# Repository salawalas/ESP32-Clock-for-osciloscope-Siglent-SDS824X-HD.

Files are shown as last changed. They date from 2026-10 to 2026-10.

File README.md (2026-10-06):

# Zegar RTC dla Siglent SDS800X HD (ESP32 + DS3231 + W5500)

Pudełko, które po włączeniu wysyła do oscyloskopu aktualną datę i godzinę (SCPI po TCP, port 5025).
Czas pochodzi z DS3231 (działa bez sieci), a gdy w zasięgu jest skonfigurowane Wi-Fi, jest odświeżany z NTP.

## Połączenia (ESP32 DevKit C)

| Moduł  | Pin modułu | GPIO ESP32 |
|---|---|---|
| DS3231 | SDA / SCL | 21 / 22 |
| W5500  | SCLK | 18 |
| | MISO | 19 |
| | MOSI | 23 |
| | SCS | 5 |
| | INT | 4 |
| | RST | 16 |
| oba | zasilanie, GND | 3V3 (lub 5V wg opisu na module W5500 - tylko jedno z nich), GND |

Piny zmienisz w `main/pins.h`. Kabel Ethernet idzie prosto z W5500 do portu LAN oscyloskopu.
Przycisk BOOT na płytce = "wyślij czas do oscyloskopu teraz".

## Ustawienia w oscyloskopie

LAN: stały adres IP `192.168.77.2`, maska `255.255.255.0`, brama pusta. Wyłącz w menu daty/czasu
synchronizację NTP przy starcie, żeby nie nadpisywała czasu z pudełka.

## Budowanie

ESP-IDF >= 5.3 (testowane tylko na papierze, patrz uwaga na końcu):

    idf.py set-target esp32
    idf.py build flash monitor

Sterownik W5500:
- IDF 5.3-5.5: wbudowany; `sdkconfig.defaults` go włącza (menuconfig -> Component config -> Ethernet -> SPI Ethernet -> W5500).
- IDF >= 6.0: sterownik jest osobnym komponentem `espressif/w5500`; pobiera go menedżer komponentów
  na podstawie `main/idf_component.yml` (przy pierwszym buildzie potrzebny internet).

PlatformIO: w `platformio.ini` jest `src_dir = main`, więc nic nie trzeba przenosić.

## Konfiguracja (konsola szeregowa, 115200)

Ustawienia trafiają do NVS i przetrwają restart. Przykład:

    set wifi_ssid MojaSiec
    set wifi_pass tajnehaslo
    set wifi_ip 192.168.1.50
    set wifi_mask 255.255.255.0
    set wifi_gw 192.168.1.1
    set wifi_dns 192.168.1.1
    set ntp_server pool.ntp.org
    set tz CET-1CEST,M3.5.0,M10.5.0/3
    sync

Inne komendy: `show`, `time`, `settime RRRR-MM-DD GG:MM:SS` (czas lokalny), `push`, `scope <SCPI>`,
`factory`, `reboot`. Wartości ze spacjami podawaj w cudzysłowie.

## Format komend SCPI

Zgodnie z Programming Guide (SDS800X HD) oscyloskop przyjmuje datę i czas jako liczby bez separatorów:
`:SYSTem:DATE 20191220` (RRRRMMDD) i `:SYSTem:TIME 081040` (GGMMSS). Domyślne wzorce w firmware
(`scope_date_fmt`, `scope_time_fmt`) to odpowiednio `:SYSTem:DATE %Y%m%d` i `:SYSTem:TIME %H%M%S`.
Wzorce są w formacie `strftime` i zmienisz je bez rekompilacji, np. `set scope_date_fmt "..."`.
Odczyt kontrolny: `scope :SYSTem:DATE?` i `scope :SYSTem:TIME?`; po każdej wysyłce widać go też w logu.

## Zachowanie

- Start: czas z DS3231 -> zegar systemowy -> wysyłka do oscyloskopu (ponawiana co 3 s przez 10 min,
  bo oscyloskop startuje wolniej niż ESP32).
- Jeśli `wifi_ssid` jest ustawione i `wifi_boot` = 1: równolegle próba Wi-Fi + NTP; po sukcesie czas jest
  zapisywany do DS3231 (UTC) i wysyłany do oscyloskopu ponownie, a Wi-Fi jest wyłączane.
- W terenie, przy zasilaniu z USB oscyloskopu, rozważ `set wifi_boot 0` (mniejszy pobór prądu).
- Każde podniesienie linku Ethernet (np. restart oscyloskopu przy zasilaniu pudełka z powerbanku) wywołuje
  ponowną wysyłkę czasu; przycisk BOOT nadal działa jako ręczne wymuszenie.
- `scope_resync` (minuty) włącza okresowe ponawianie wysyłki, domyślnie 0.

Uwaga: konwersja daty (`timeutil.h`) była testowana na PC; reszta - na sprzęcie przez użytkownika, w toku.

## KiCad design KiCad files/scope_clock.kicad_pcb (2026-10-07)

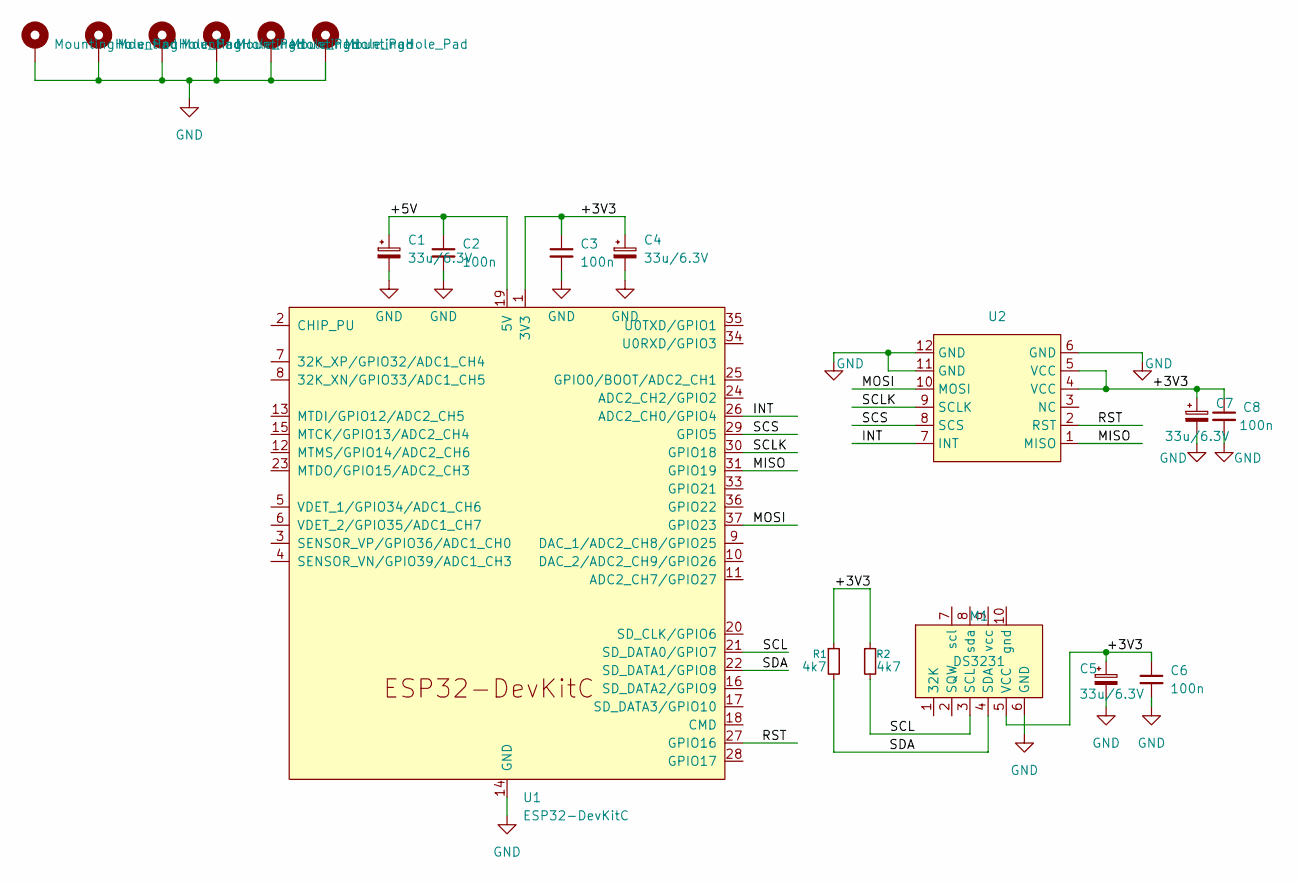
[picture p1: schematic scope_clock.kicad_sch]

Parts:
C1, C4, C5, C7: 33u/6.3V; CP_Radial_Tantal_D4.5mm_P5.00mm
C2, C3, C6, C8: 100n; C_0805_2012Metric_Pad1.18x1.45mm_HandSolder
H1, H2, H3, H4, H5, H6: MountingHole_Pad; MountingHole_2.5mm_Pad_TopBottom
M1: DS3231; DS3231_module_H
R1, R2: 4k7; R_0805_2012Metric_Pad1.20x1.40mm_HandSolder
U1: ESP32-DevKitC; ESP32-DevKitC-USB-C_MOD
U2: W5500_module_Mini

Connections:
/+3V3: C3.1, C4.1, C5.1, C6.1, C7.1, C8.1, M1.5 (VCC), R1.1, R2.1, U1.1 (3V3), U2.4 (VCC), U2.5 (VCC)
/+5V: C1.1, C2.1, U1.19 (5V)
/INT: U1.26 (ADC2_CH0/GPIO4), U2.7 (INT)
/MISO: U1.31 (GPIO19), U2.1 (MISO)
/MOSI: U1.37 (GPIO23), U2.10 (MOSI)
/RST: U1.27 (GPIO16), U2.2 (RST)
/SCL: M1.3 (SCL), R2.2, U1.21 (SD_DATA0/GPIO7)
/SCLK: U1.30 (GPIO18), U2.9 (SCLK)
/SCS: U1.29 (GPIO5), U2.8 (SCS)
/SDA: M1.4 (SDA), R1.2, U1.22 (SD_DATA1/GPIO8)
GND: C1.2, C2.2, C3.2, C4.2, C5.2, C6.2, C7.2, C8.2, H1.1 (1_1), H2.1 (1_1), H3.1 (1_1), H4.1 (1_1), H5.1 (1_1), H6.1 (1_1), M1.6 (GND), U1.14 (GND), U1.32 (GND), U1.38 (GND), U2.6 (GND), U2.11 (GND), U2.12 (GND)

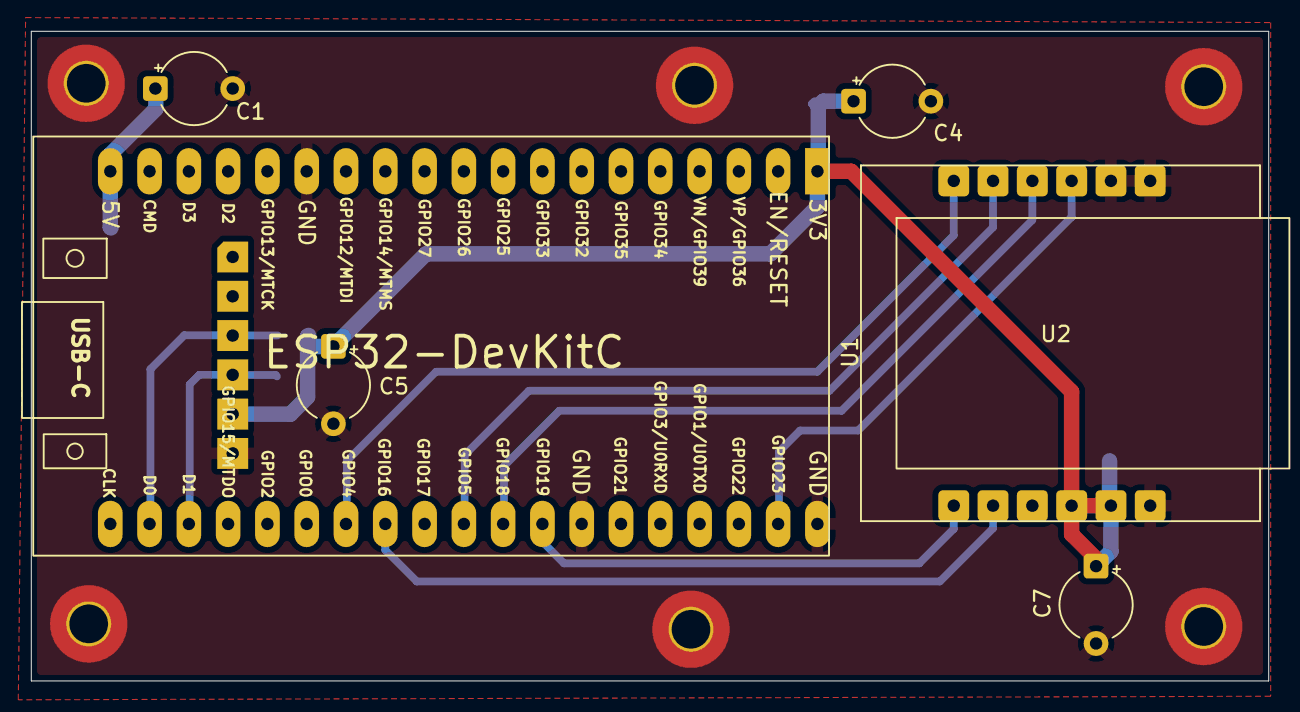
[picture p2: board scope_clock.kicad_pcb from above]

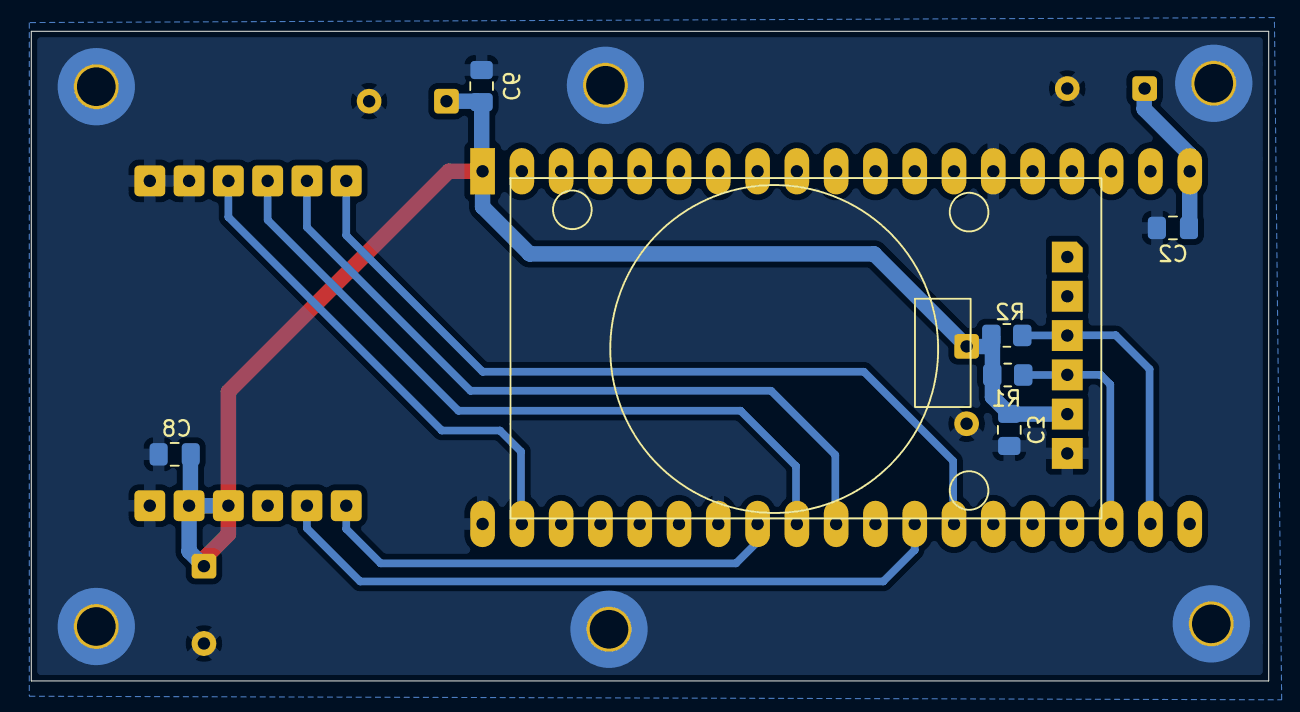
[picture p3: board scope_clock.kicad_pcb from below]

Board: 2 copper layers, 80.0 x 42.0 mm, 19 parts (7 on the bottom side), 11 nets.

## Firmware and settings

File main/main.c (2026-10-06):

#include <stdlib.h>
#include <sys/time.h>
#include "app.h"
#include "cfg.h"
#include "cli.h"
#include "net_eth.h"
#include "net_wifi.h"
#include "pins.h"
#include "rtc_ds3231.h"
#include "scope.h"
#include "driver/gpio.h"
#include "esp_event.h"
#include "esp_log.h"
#include "esp_netif.h"
#include "nvs_flash.h"

static const char *TAG = "main";

EventGroupHandle_t g_evt;
volatile bool g_time_valid;

void app_set_system_utc(time_t utc)
{
    struct timeval tv = { .tv_sec = utc, .tv_usec = 0 };
    settimeofday(&tv, NULL);
    g_time_valid = true;
}

void app_apply_tz(void)
{
    setenv("TZ", cfg_get("tz"), 1);
    tzset();
}

/* Przycisk BOOT: wymusza ponowna wysylke czasu (np. po restarcie samego oscyloskopu) */
static void button_task(void *arg)
{
    gpio_config_t io = {
        .pin_bit_mask = 1ULL << PIN_BTN_PUSH,
        .mode = GPIO_MODE_INPUT,
        .pull_up_en = GPIO_PULLUP_ENABLE,
    };
    gpio_config(&io);
    bool prev = true;
    for (;;) {
        bool lvl = gpio_get_level(PIN_BTN_PUSH);
        if (prev && !lvl) {
            vTaskDelay(pdMS_TO_TICKS(30));                    /* debounce */
            if (!gpio_get_level(PIN_BTN_PUSH)) {
                ESP_LOGI(TAG, "przycisk BOOT -> wysylam czas do oscyloskopu");
                xEventGroupSetBits(g_evt, EVT_PUSH_SCOPE);
            }
        }
        prev = lvl;
        vTaskDelay(pdMS_TO_TICKS(20));
    }
}

void app_main(void)
{
    esp_err_t err = nvs_flash_init();
    if (err == ESP_ERR_NVS_NO_FREE_PAGES || err == ESP_ERR_NVS_NEW_VERSION_FOUND) {
        ESP_ERROR_CHECK(nvs_flash_erase());
        err = nvs_flash_init();
    }
    ESP_ERROR_CHECK(err);
    ESP_ERROR_CHECK(esp_netif_init());
    ESP_ERROR_CHECK(esp_event_loop_create_default());

    g_evt = xEventGroupCreate();
    cfg_load();
    app_apply_tz();

    /* 1. Czas z DS3231 (dziala bez zadnej sieci) */
    if (ds3231_init(PIN_I2C_SDA, PIN_I2C_SCL) == ESP_OK) {
        time_t t;
        bool osf;
        if (ds3231_get_utc(&t, &osf) == ESP_OK) {
            if (!osf && t >= TIME_MIN_VALID) {
                app_set_system_utc(t);
                ESP_LOGI(TAG, "czas z DS3231 poprawny");
            } else {
                ESP_LOGW(TAG, "DS3231: czas niewiarygodny (OSF/data) - potrzebna synchronizacja ('sync' / 'settime')");
            }
        }
    } else {
        ESP_LOGE(TAG, "DS3231 niedostepny - sprawdz SDA/SCL; czas tylko z NTP");
    }

    /* 2. Ethernet do oscyloskopu */
    if (eth_start() != ESP_OK)
        ESP_LOGE(TAG, "Ethernet (W5500) nie wystartowal - sprawdz okablowanie i menuconfig");

    /* 3. Zadania */
    scope_start();
    wifi_sync_start();
    xTaskCreate(button_task, "button", 2048, NULL, 3, NULL);
    cli_start();

    /* 4. Pierwsze akcje po starcie */
    if (g_time_valid) xEventGroupSetBits(g_evt, EVT_PUSH_SCOPE);
    if (cfg_get_u32("wifi_boot") && cfg_get("wifi_ssid")[0]) xEventGroupSetBits(g_evt, EVT_WIFI_SYNC);
}

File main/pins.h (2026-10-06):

#pragma once
/* Piny dla ESP32 DevKit C (ESP32-WROOM-32). Zmien tutaj, jesli podlaczysz inaczej. */

/* DS3231 (I2C) */
#define PIN_I2C_SDA     21
#define PIN_I2C_SCL     22

/* W5500 (SPI) - VSPI, natywne piny IOMUX */
#define ETH_SPI_HOST    SPI3_HOST
#define ETH_SPI_MHZ     10          /* 10 MHz jest bezpieczne na kabelkach; na krotkich polaczeniach mozna 20 */
#define PIN_ETH_SCLK    18
#define PIN_ETH_MISO    19
#define PIN_ETH_MOSI    23
#define PIN_ETH_CS      5           /* na module W5500 opisany jako SCS */
#define PIN_ETH_INT     4
#define PIN_ETH_RST     16          /* WROVER: 16/17 zajete przez PSRAM - wtedy zmien */

/* Przycisk BOOT na DevKit C: krotkie nacisniecie = wyslij czas do oscyloskopu */
#define PIN_BTN_PUSH    0
